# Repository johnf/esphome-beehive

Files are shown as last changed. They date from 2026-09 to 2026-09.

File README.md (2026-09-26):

# ESP32 Beehive Monitor

A battery-powered beehive monitoring system built with ESPHome. Uses FFT-based
audio analysis to detect colony health indicators, along with weight,
temperature, and humidity monitoring.

## Features

- **Audio Analysis**: FFT-based frequency band monitoring to detect queen
  piping, queenless conditions, and pre-swarm behaviour
- **Weight Monitoring**: Track hive weight changes using 4x 50kg load cells via
  NAU7802 ADC
- **Environmental Sensing**: Temperature and humidity via SHT40 sensor
- **Power Monitoring**: Solar current, voltage and power via INA226; battery voltage
  and state of charge via the FeatherS3D's onboard MAX17048 fuel gauge
- **Battery Optimised**: Deep sleep between 5-minute measurement cycles
- **Home Assistant Integration**: Automatic sensor discovery and state reporting

## Hardware Requirements

| Component | Description | Qty |
| --- | --- | ----- |
| [FeatherS3D](https://unexpectedmaker.com/feathers3d) (ESP32-S3) | Main microcontroller | 1 |
| INMP441 | I2S MEMS microphone (GPIO1, 3, 7) | 1 |
| [Adafruit NAU7802](https://www.adafruit.com/product/4538) | 24-bit ADC breakout | 1 |
| 50kg Load Cells | Half-bridge strain gauges | 4 |
| SHT40 | Temperature/humidity sensor | 1 |
| INA226 | Solar current/voltage/power monitor | 1 |
| CN3065 | Solar LiPo charge controller | 1 |
| [3.7V 2000mAh LiPo](https://core-electronics.com.au/polymer-lithium-ion-battery-2000mah-38459.html) | Battery (DW01+ PCM) | 1 |
| Solar panel | 6V nominal, 1W or larger (CN3065 input is rated for 6V panels) | 1 |
| Stripboard 24 x 41 holes | Main board (under the bottom board) | 1 |
| Stripboard 16 x 15 holes | Hive board (inside the brood box) | 1 |
| JST-XH 8-way socket and cable | Hive cable, one socket per board | 2 sockets, 1 cable |
| JST-XH 12-way socket and cable | Load cell socket (J_CELLS) | 1 |
| JST-XH 2-way socket | Solar in, charger in, charger out | 3 |
| JST-PH 2-way pigtail | CN3065 solar and output sockets | 2 |
| 100 nF ceramic capacitor | C2, C3 | 2 |
| 470 µF 6.3 V electrolytic capacitor | C1 | 1 |

## Power Architecture

The battery is charged by the CN3065 solar charge controller. An INA226 sits
high-side between the solar panel and the CN3065 solar input. The battery connects
directly to the CN3065 battery terminal.

The CN3065 output feeds the FeatherS3D's **VBAT pin**, so the board's own LDO
regulates 3.3V. Feeding the 3.3V pin instead would leave LDO2 unpowered, as its
input is the VBAT/USB node rather than the 3.3V rail.

The FeatherS3D's onboard charger only has power while USB is plugged in, so in the
field the CN3065 is the only charger. On USB, both chargers are 4.2V CC/CV parts and
share the cell harmlessly, with the DW01+ PCM as a backstop.

Battery voltage and state of charge come from the FeatherS3D's onboard MAX17048 fuel
gauge (I2C 0x36), which sees the cell via the VBAT pin. It sits on the always-on
LDO1 rail, so its ModelGauge state survives deep sleep.

The FeatherS3D's **LDO2** (GPIO39) provides a switchable 3.3V rail that is automatically
disabled during deep sleep, used to power-gate sensors that aren't needed during sleep.
All sensors, including the I2C pull-ups on their breakouts, are on this rail.

The INA226 address pins A0 and A1 are left unconnected. The CJMCU-226 module
has 10 kΩ pull-downs on both, which gives address 0x40. Confirm this on your
unit before building: unpowered, A0 to GND and A1 to GND should each read about
10 kΩ. If either reads open, strap that pad to GND.

CJMCU-226 modules come with two header pinouts: after ALE some read SDA then
SCL, others SCL then SDA. The Fritzing part (`fritzing/ina226/`) and the
stripboard layout follow the first, with SDA on pin 5. Check the silkscreen
before soldering the header; if yours is the other variant, do not plug the
module straight into its socket, but cross SDA and SCL with two short flying
leads.

### Solar Performance

The CN3065 regulates its own input voltage. In direct sun it held the panel at
4.77V for over an hour while the current drifted, well below the 6V maximum
power point of a nominal 6V panel. Panel power is therefore capped near 0.8W no
matter how much sun a 1W panel sees.

That cap matters less than it looks. The CN3065 is a linear charger, so it
passes current through roughly one-for-one and burns the voltage difference as
heat. Charge current, not panel watts, is what fills the cell.

Measured on a 110 x 60 mm 1W 6V polycrystalline panel in direct spring sun
(Sydney, sun about 52° above the horizon, panel not aimed):

| Quantity | Value |
|---|---|
| Panel voltage | 4.77V (clamped by the CN3065) |
| Panel current | 113-121 mA |
| Panel power | 0.54-0.58W |
| Fraction of nameplate | 55-58% |

At ~113 mA against an average draw of ~2.3 mA, roughly half an hour of direct
sun per day covers the device's entire daily consumption, and four good hours
put in over eight times what it uses. A 1W panel is ample for this load.

Siting buys far more than panel size. The same panel shaded and badly angled
produced 5-50 mW, one to two orders of magnitude below its direct-sun output,
and the battery fell 2.7% per day through it. If the battery is losing ground,
move the panel before buying a bigger one.

If you do want more margin, wire two panels in **parallel** to roughly double
the current at the clamped voltage. Series gains nothing, because the charger
regulates its input down regardless of what the panels could deliver.

### Battery Specifications

| Parameter | Value |
|---|---|
| Nominal voltage | 3.7V |
| Charge voltage | 4.2V (CN3065) |
| Overcharge protection | 4.30V ±0.05V (DW01+ PCM) |
| Over-discharge protection | 2.4V ±0.1V (DW01+ PCM) |
| Capacity | 2000mAh |
| Wiring/connector rating | 1A max |

### I2C Address Map

| Address | Device |
|---|---|
| 0x2A | NAU7802 (load cell ADC) |
| 0x36 | MAX17048 fuel gauge (onboard FeatherS3D) |
| 0x40 | INA226 (solar) |
| 0x44 | SHT40 (temperature/humidity) |

## Wiring

The circuit is split across two stripboards joined by a pluggable cable. The
Fritzing sketch `fritzing/BeeHive.fzz` is the design of record and its
breadboard view holds the stripboard layout. Both boards use vertical strips
(strips run top to bottom in the breadboard view) and hole coordinates below
are `(column, row)` counted from 0 at the top-left.

### Boards and Connectors

**Main board** (24 x 41, under the bottom board with the battery, CN3065 and
solar panel plug): FeatherS3D, INA226, NAU7802, C1, C2 and five sockets. The
Feather sits across the top with its 16-pin row on row 3 and 12-pin row on
row 11; every strip under those rows is cut above the top row and below the
bottom row (cuts `x.3v` and `x.10v` for columns 3-18 and 3-14) so the two rows
do not short, except column 15, which carries the Feather GND pin the full
height of the board as the ground rail. Column 2 is the 3.3 V rail, fed from
LDO2 (column 3, row 3) by the jumper on row 2.

Columns 2-9 run straight from the Feather's bottom row to J_HIVE on the bottom
edge (row 40), so 3V3, SDA, SCL, WS, SCK and SD reach the hive socket without a
jumper; columns 5 and 6 (IO33 and IO38, cut at `5.11v 6.11v`) become its two
ground pins via row 14. Everything else sits to the right of that corridor:
C1 and the VBAT tap at the top right, J_PWR on the right edge at row 15, the
INA226 with its header on row 18 (VCC, GND, SCL, SDA, ALE, VBS, IN-, IN+ on
columns 14-21, GND landing on the rail, C2 directly above it on row 17),
J_SOLAR and J_CHG on the right edge at rows 28 and 31, the NAU7802 with its
header on row 29 (DRDY, SDA, SCL, GND, AVDD, VCC on columns 12-17, GND on the
rail, screw terminal facing the bottom edge) and J_CELLS on the bottom edge
beside J_HIVE. Column 23 is a second ground rail for C1 and the three
right-edge sockets; column 22 carries VBAT, panel + and charger + in three
segments. Row 39 stays empty under the two bottom sockets.

| Row | Jumper | Net |
| --- | --- | --- |
| 2 | (3,2) → (2,2) | LDO2 to the 3.3 V rail |
| 12 | (14,12) → (22,12) | VBAT to C1 and J_PWR |
| 13 | (2,13) → (14,13) | 3.3 V to INA226 VCC and C2 |
| 13 | (15,13) → (23,13) | Ground to the right rail |
| 14 | (15,14) → (6,14) → (5,14) | Ground to J_HIVE pins 4 and 5 |
| 15 | (4,15) → (16,15) | SCL to the INA226 |
| 16 | (3,16) → (13,16) → (17,16) | SDA to the NAU7802 and INA226 |
| 26 | (14,26) → (17,26) | 3.3 V to NAU7802 VCC |
| 26 | (19,26) → (20,26) | INA226 VBS to IN- |
| 26 | (21,26) → (22,26) | INA226 IN+ to J_SOLAR + |
| 27 | (16,27) → (14,27) | SCL to the NAU7802 |
| 33 | (20,33) → (22,33) | INA226 IN- to J_CHG + |
| 38 | (12,38) → (13,38), (15,38) → (16,38), (18,38) → (19,38), (21,38) → (22,38) | Load cell ring, see [Load Cells](#load-cells) |
| 38 | (11,38), (14,38), (17,38), (20,38) | Flying leads into the NAU7802 screw terminal |

**Hive board** (16 x 15, inside the brood box): SHT40, INMP441, C3 and the
cable socket. It is wired up the inside of the hive and unplugs at the main
board.

| Socket | Board, holes | Pin 1 | Pin 2 | Pin 3 | Pin 4 | Pin 5 | Pin 6 | Pin 7 | Pin 8 |
| --- | --- | --- | --- | --- | --- | --- | --- | --- | --- |
| J_HIVE | Main (2-9, 40) | 3V3 | SDA | SCL | GND | GND | WS | SCK | SD |
| J_SUB | Hive (2-9, 1) | 3V3 | SDA | SCL | GND | GND | WS | SCK | SD |
| J_SOLAR | Main (22-23, 28) | Panel + | Panel - | | | | | | |
| J_CHG | Main (22-23, 31) | CN3065 SOLAR + | CN3065 SOLAR - | | | | | | |
| J_PWR | Main (22-23, 15) | CN3065 OUT + | CN3065 OUT - | | | | | | |
| J_CELLS | Main (11-22, 40) | 12 pins, see [Load Cells](#load-cells) | | | | | | | |

The hive cable is wired pin for pin. Ground sits between SCL and the I2S
clocks so the cable can run a metre or two. JST-XH is 2.5 mm pitch, which
fits the 2.54 mm stripboard grid with a little lean on the 8-way socket and
about half a millimetre over the 12-way. Every socket sits on a board edge, so
side-entry (S*B-XH-A) or top-entry (B*B-XH-A) housings both work.

The CN3065 module is not on the stripboard. Its three JST-PH sockets take the
panel current from J_CHG (after the INA226 shunt), the battery directly, and
send the output to J_PWR via short pigtails. The INA226 address pads A0 and A1
are left open; the module pulls them down (see Power Architecture).

Strip cuts on the main board beyond the Feather rows: `5.11v 6.11v` turn the
IO33 and IO38 strips into the J_HIVE grounds, `14.12v` separates VBAT from the
3.3 V segment that feeds the INA226, `13.15v 16.14v 17.15v` keep the SDA and
SCL taps off the Feather pins and pads above them, `17.25v 14.26v 16.27v
12.28v` split the INA226 columns from the NAU7802 header (VCC, SCL, AVDD and
DRDY), `22.15v 22.29v` divide column 22 into VBAT, panel + and charger +, and
`11.37v` to `22.37v` isolate the J_CELLS pins (rows 38-40) from everything
above them. On the hive board the cuts are `6.4v` (SHT40 VIN off the ground
strip) and `10.6v 11.6v` (the microphone's top and bottom pin rows). The
sketch has the jumper wires and exact placements; check the build against it
with `python3 .claude/skills/circuit/fzz_nets.py fritzing/BeeHive.fzz`.

### I2C Bus (SHT40, NAU7802, INA226, MAX17048)

The I2C bus must be defined in your device configuration and its `id` passed to the
package via the `i2c_bus_id` substitution (defaults to `i2c_bus`).

| Signal | Default GPIO |
| --- | --- |
| SDA | GPIO8 |
| SCL | GPIO9 |

### INMP441 Microphone

Pin assignments are configurable via substitutions (`i2s_lrclk_pin`, `i2s_bclk_pin`, `i2s_din_pin`).

| INMP441 Pin | Default ESP32 GPIO |
| --- | --- |
| WS (LRCLK) | GPIO1 |
| SCK (BCLK) | GPIO3 |
| SD (DOUT) | GPIO7 |
| VDD | 3.3V |
| GND | GND |
| L/R | GND (left channel) |

### Load Cells

Each 50kg half-bridge cell has three wires: red (centre tap), white and black.
All twelve go to J_CELLS, the 12-way JST-XH socket on the bottom edge of the
main board. The bridge is made on the board, so nothing is spliced at the
platform. Place one cell at each corner and number them 1 to 4 clockwise.

| J_CELLS pin | Wire | J_CELLS pin | Wire |
| --- | ---- | --- | ---- |
| 1 | Cell 1 red | 7 | Cell 3 red |
| 2 | Cell 1 white | 8 | Cell 3 white |
| 3 | Cell 2 white | 9 | Cell 4 white |
| 4 | Cell 2 red | 10 | Cell 4 red |
| 5 | Cell 2 black | 11 | Cell 4 black |
| 6 | Cell 3 black | 12 | Cell 1 black |

The jumpers on row 38 bridge pins 2-3, 5-6, 8-9 and 11-12, joining like
colours round the platform (white 1-2, black 2-3, white 3-4, black 4-1) into a
full Wheatstone bridge. Like must join like: in each cell the white and black
halves change in opposite directions under load, so a white-to-black ring
cancels in every bridge arm and the output barely moves. The four red wires
land on row 38 under the NAU7802 screw terminal and run into it with short
leads:

| Cell (red wire) | Row 38 hole | NAU7802 |
| --- | --- | --- |
| Cell 1 | (11,38) | E+ |
| Cell 2 | (14,38) | A- |
| Cell 3 | (17,38) | E- |
| Cell 4 | (20,38) | A+ |

E+ and E- are the bridge excitation (the breakout's AVDD and GND); A- and A+
are the channel A input. The B- and B+ terminals are the unused channel B.

If the weight reads negative when load is added, swap A+ and A-.

### Capacitors

| Ref | Value | Placement |
| --- | ----- | --- |
| C1 | 470 µF electrolytic, 6.3 V | VBAT and GND strips at the top right, main board (22-23, 11) |
| C2 | 100 nF ceramic | INA226 VCC and GND strips directly above its header, main board (14-15, 17) |
| C3 | 100 nF ceramic | INMP441 VDD and GND strips, hive board (11-12, 10) |

C1 stops WiFi transmit bursts browning out the LDO when the cell is cold or low.
C2 and C3 must sit right at the module pins; long wires in a beehive pick up
noise, and the INMP441 feeds the FFT analysis. The NAU7802 and SHT40 breakouts
have onboard decoupling already.

## Enclosure

`case/beehive-case.scad` is a parametric OpenSCAD model of two enclosures, with
exported STLs in `case/stl/`. Every dimension is a named variable at the top of
the file.

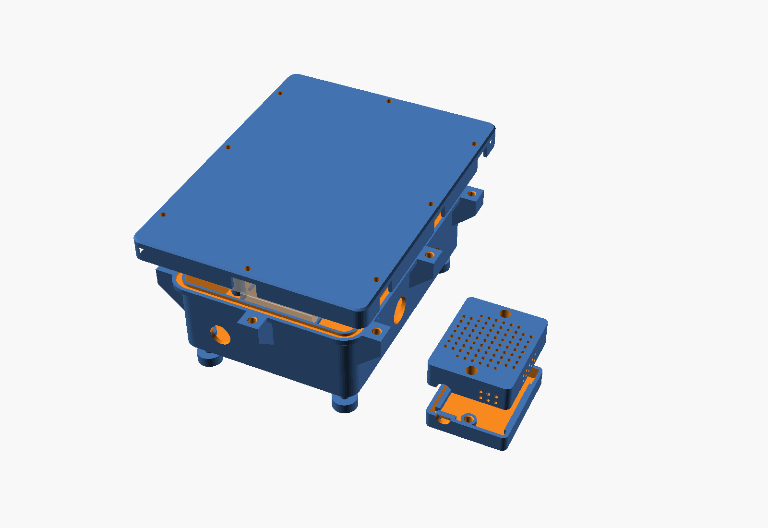
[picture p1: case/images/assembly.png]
Assembly


The `layout` view shows where the boards, battery and charger sit:

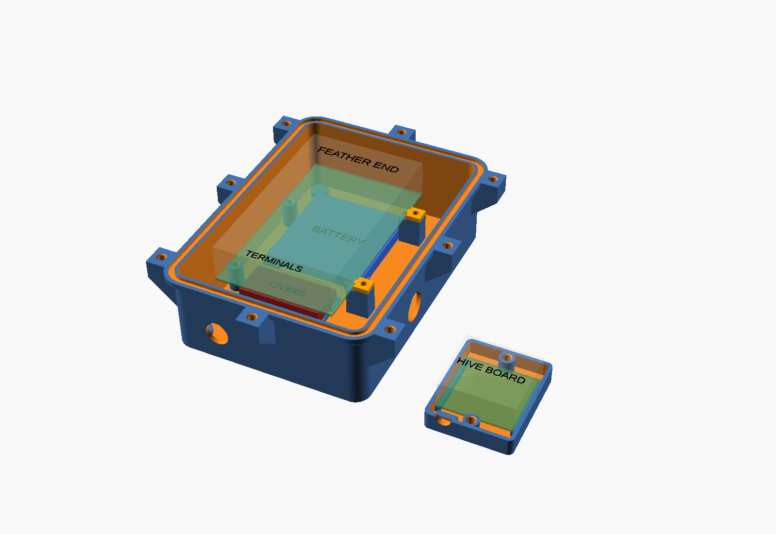
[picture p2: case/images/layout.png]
Layout

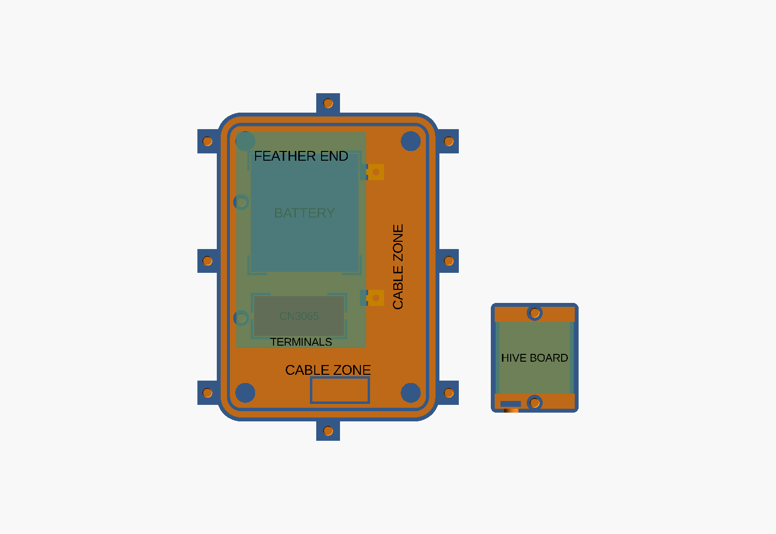
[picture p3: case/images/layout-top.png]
Layout from above


After changing a dimension, re-export the STLs and images:

```bash
cd case
for p in box lid clamp foot hive_base hive_lid; do
  openscad -D "part=\"$p\"" -o stl/$p.stl beehive-case.scad
done
openscad -D 'part="layout"' --camera=0,0,0,50,0,25,600 --viewall --autocenter \
  --imgsize=1600,1100 --colorscheme=Tomorrow -o images/layout.png beehive-case.scad
openscad -D 'part="layout"' --camera=0,0,0,0,0,0,600 --projection=ortho --viewall \
  --autocenter --imgsize=1600,1100 --colorscheme=Tomorrow -o images/layout-top.png \
  beehive-case.scad
openscad -D 'part="assembly"' --camera=0,0,0,50,0,25,600 --viewall --autocenter \
  --imgsize=1600,1100 --colorscheme=Tomorrow -o images/assembly.png beehive-case.scad
openscad -D 'part="seal_section"' --camera=0.99,37.98,0,0,0,0,40 --projection=ortho \
  --imgsize=1600,1100 --colorscheme=Tomorrow -o images/seal-section.png \
  beehive-case.scad
for p in hive_base hive_lid; do
  openscad -D "part=\"$([ $p = hive_lid ] && echo hive_lid_fitted || echo $p)\"" \
    --camera=0,0,0,50,0,25,150 --viewall --autocenter --imgsize=1600,1100 \
    --colorscheme=Tomorrow -o images/${p/_/-}.png beehive-case.scad
done
```

Then slice every STL with PrusaSlicer to catch parts that don't fit the bed or
need supports. `a1mini.ini` approximates the A1 mini with the settings below and
gives print times and filament use:

```bash
for p in box lid clamp foot hive_base hive_lid; do
  prusa-slicer --export-gcode --load a1mini.ini --center 90,90 \
    -o /tmp/$p.gcode stl/$p.stl 2>&1 | grep -A3 -i warning
done
```

`hive_lid` reports "Floating bridge anchors": that is the one-layer bridge over
each counterbore that you drill out, and it prints fine.

Open `beehive-case.scad` in OpenSCAD with `part = "layout"` to rotate the layout
view yourself. Colours only show in preview (F5), not in a full render (F6).

**Main box** sits under the hive and holds the main board, battery and CN3065.
The board rides on two M3 posts down its left edge and two printed clamps on its
right edge, with the battery and charger underneath. There is 30 mm clearance on
the terminal edges. Cables enter through two PG9 glands and a PG7 on one long wall; an
M12 ePTFE vent on the end wall lets it breathe without leaving a gap for ants. A
2.4 mm O-ring sits in a groove in the rim. The lid closes flush on the rim,
which squeezes the ring 25%, and screws into heat-set inserts in eight lugs. A
skirt under the lid locates it inside the walls, and a lip around its edge
stiffens it and keeps rain off the rim.

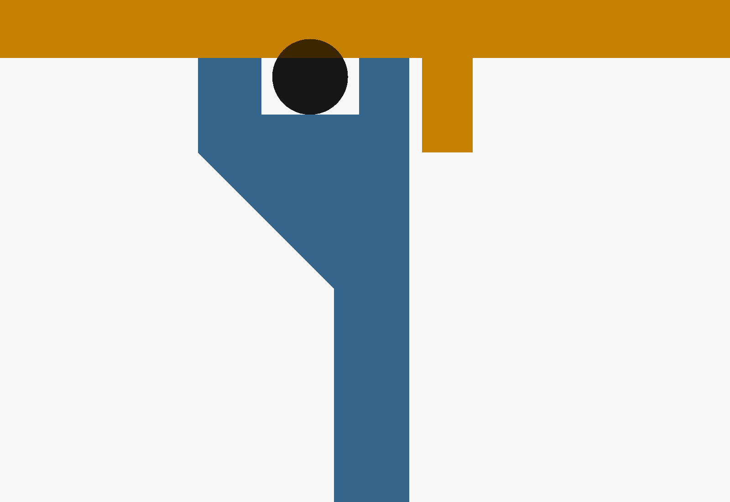
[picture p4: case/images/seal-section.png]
Seal cross-section


The seal is a 155 mm OD x 2.4 mm nitrile O-ring (about 150 mm ID). It stretches
about 2% to fit the groove, whose centre line is 488 mm (`groove_len`). A larger
2.4 mm ring or cord also works: cut it to 488 mm and butt-join the ends with
cyanoacrylate. For a different cross-section, change `oring_d`, `groove_depth`
(0.75 x the cross-section, rounded to a multiple of the layer height) and
`groove_w` (1.3 x).

**Hive housing** sits loose on the mesh floor inside the brood box. The base is
solid so the SHT40 reads hive air, not air through the mesh. The board rests on
ledges and ribs on the lid's side walls hold it down. The top and sides are a
grid of 2 mm holes, too small for bees. The Cat6 leaves through a notch at one
end, tied to an anchor.

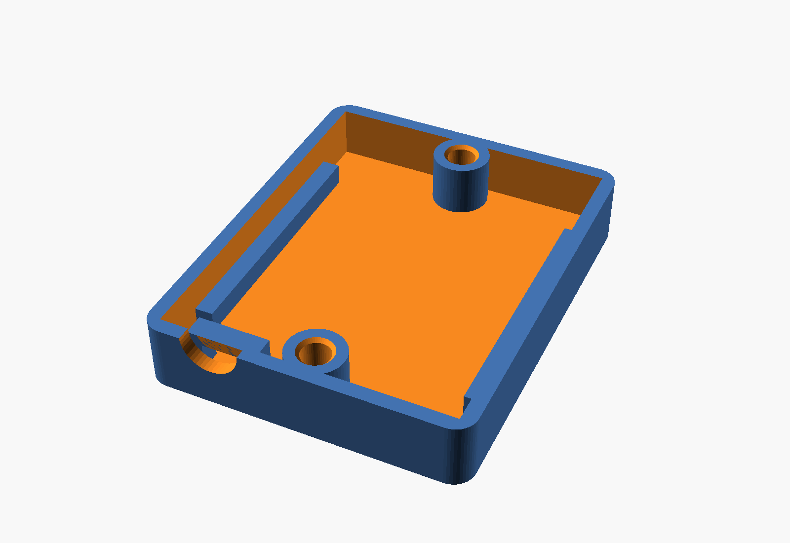
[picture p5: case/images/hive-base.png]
Hive housing base

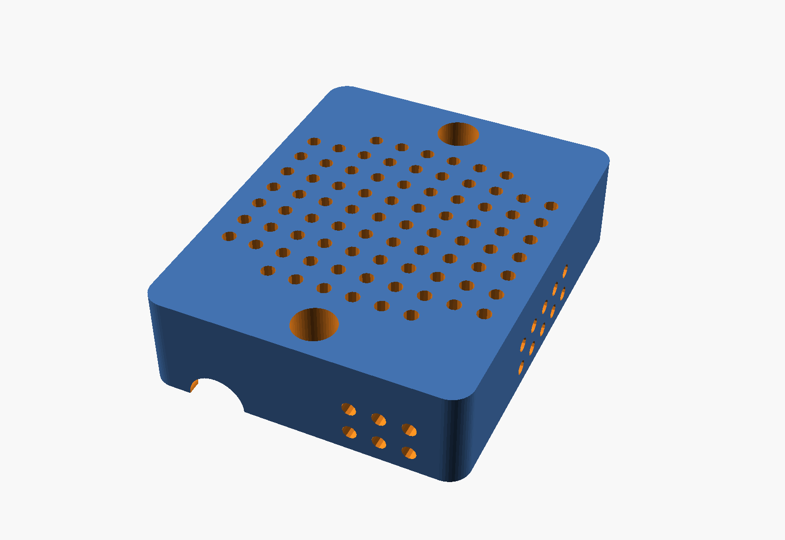
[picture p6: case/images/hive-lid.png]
Hive housing lid


Print in PLA, starting from the A1 mini 0.20 mm Standard profile with 4 wall
loops, 35% infill and no brim (`box` and `lid` are 175 mm long on a 180 mm
bed). Iron the top surface of `lid`, which is its sealing face. Print `lid` and
`hive_lid` as exported (outside face down). Each screw hole in `hive_lid` has a one-layer
bridge at the bottom of its counterbore; push a 3 mm drill through it after
printing. Press the heat-set inserts into the lid lugs, board posts, clamp
towers and hive housing posts with a soldering iron before assembly, flush or
just below the surface; the lid must sit flat on the lugs.

| Part | Qty |
| ---- | --- |
| `box`, `lid`, `hive_base`, `hive_lid` | 1 each |
| `clamp` | 2 |
| `foot` (glue into the floor) | 4 |
| PG9 cable gland, 4-8 mm (load cells, Cat6) | 2 |
| PG7 cable gland, 3-6.5 mm (solar) | 1 |
| M12 ePTFE breather vent | 1 |
| M3 x 10 socket head cap screw, stainless | 14 |
| M3 x 5.7 mm heat-set insert, 4.0 mm hole (e.g. ruthex) | 14 |
| O-ring, 155 mm OD x 2.4 mm, nitrile | 1 |
| Adhesive-lined heatshrink (load cell bundle, solar pair) | 2 |
| Silica gel sachet | 1 |
| Removable double-sided mounting strip (battery to floor, e.g. 3M Command) | 1 |

Drill the main board's two M3 holes in the outer left column, 15 mm and 73 mm
from the bottom edge. If you drill elsewhere, update `left_holes_y`.

## Installation

### Prerequisites

- Home Assistant with the ESPHome add-on installed

### Setup

1. **Create a new device in ESPHome**

   - Open the ESPHome dashboard in Home Assistant
   - Click **+ New Device**
   - Choose **Continue** then **Skip this step** (we'll use our own config)
   - Enter a name (e.g., `beehive-monitor`) and click **Next**
   - Select **ESP32** as the device type
   - Click **Skip** to skip the installation for now

2. **Edit the configuration**

   Click **Edit** on the new device and use the following configuration:

   ```yaml
   # Include the beehive monitoring package. `refresh: always` re-fetches the
   # default branch on every run instead of using ESPHome's cached copy.
   packages:
     beehive:
       url: https://github.com/johnf/esphome-beehive
       files: [beehive-monitor.yaml]
       refresh: always

   # Device configuration (required)
   esphome:
     name: beehive-monitor
     friendly_name: Beehive Monitor

   esp32:
     framework:
       type: esp-idf
     variant: esp32s3
     flash_size: 16MB  # FeatherS3D has 16MB flash

   psram:
     mode: quad
     speed: 80MHz

   # I2C bus (required - must define with id matching i2c_bus_id substitution)
   i2c:
     id: i2c_bus
     sda: GPIO8
     scl: GPIO9
     scan: true
     frequency: 400kHz

   # WiFi configuration (required)
   wifi:
     ssid: !secret wifi_ssid
     password: !secret wifi_password
     fast_connect: true

   # Home Assistant API (required)
   api:
     reboot_timeout: 0s

   # Optional: enable logging during development
   logger:
     hardware_uart: USB_CDC
     level: DEBUG

   # Optional: override default pin assignments, I2C addresses, calibration
   # or audio thresholds (see beehive-monitor.yaml for the full list)
   # substitutions:
   #   i2c_bus_id: "i2c_bus"
   #   i2s_lrclk_pin: "GPIO1"
   #   i2s_bclk_pin: "GPIO3"
   #   i2s_din_pin: "GPIO7"
   #   ina226_solar_address: "0x40"
   #   audio_active_threshold: "-95dB"
   ```

   A complete working example is in [example.yaml](example.yaml).

3. **Configure secrets**

   ESPHome uses Home Assistant's secrets. Add to your `secrets.yaml`:

   ```yaml
   wifi_ssid: 'YourWiFiNetwork'
   wifi_password: 'YourWiFiPassword'
   ```

   Or use the ESPHome Secrets editor (three-dot menu → **Secrets**).

4. **Install to the device**

   - Click **Install** on the device
   - For first-time installation, choose **Plug into this computer** or
     **Manual download** to get the firmware binary
   - Flash via USB using the web installer at <https://web.esphome.io/>
   - Subsequent updates can use **Wirelessly** once connected; see
     [OTA Updates](#ota-updates) for how to keep the device awake

### OTA Updates

The device is only awake for a few seconds every five minutes, which is not long
enough to install firmware wirelessly. The package therefore reads a Home
Assistant boolean helper on every wake and stays awake while it is on.

1. In Home Assistant, go to **Settings → Devices & services → Helpers**, create a
   **Toggle** helper and name it `Beehive OTA mode`, so its entity ID is
   `input_boolean.beehive_ota_mode`. Use the `ota_mode_entity` substitution if
   you pick a different name or run several hives.

   Then go to **Settings → Devices & services → ESPHome**, open the device's
   integration entry, click **Configure** and enable **Allow the device to
   perform Home Assistant actions**. The device needs this to clear the helper
   if it's left on (see below).
2. Turn the helper on. Within five minutes the device wakes, sees it, and logs
   `OTA mode - staying awake`. It keeps taking readings every
   `ota_mode_interval` (default five minutes); the **Measure Now** button
   starts a cycle straight away.
3. Click **Install → Wirelessly** in the ESPHome dashboard. Once an upload
   starts the device will not sleep until it reboots into the new firmware.
4. After the reboot the device stays awake while the helper is on, so you can
   watch the logs. Turn the helper off and the device goes back to sleep
   straight away.

If the helper is left on, the device clears it after `ota_mode_max_awake`
(default 30 minutes) and goes back to sleep. Without the actions permission
from step 1 the device still sleeps after the timeout, but stays awake again on
the next wake until you turn the helper off.

The package defines the `ota` component. To add a password or other options,
extend it in your device configuration rather than declaring a second one:

```yaml
ota:
  - id: !extend ota_esphome
    password: !secret ota_password
```

### Power Optimisation (recommended for battery operation)

For battery-powered deployments, add these settings to reduce power consumption:

```yaml
wifi:
  ssid: !secret wifi_ssid
  password: !secret wifi_password
  fast_connect: true
  power_save_mode: light
  # Static IP eliminates DHCP negotiation, saving 1-3 seconds per wake
  manual_ip:
    static_ip: 192.168.1.100  # Choose an IP outside your DHCP range
    gateway: 192.168.1.1      # Your router's IP
    subnet: 255.255.255.0

api:
  reboot_timeout: 0s  # Prevent reboots when Home Assistant is unavailable

# Disable UART logging in production
logger:
  level: WARN
  baud_rate: 0
```

## Calibration

### Load Cell Calibration

The package ships with placeholder calibration values that will not match your
load cells. Calibrate before trusting any weight reading.

1. Turn on [OTA mode](#ota-updates) so the device stays awake, and view the
   device logs in the ESPHome dashboard (click **Logs**). Each measurement
   cycle logs seven raw NAU7802 values; use the middle of the range. Cycles
   repeat every `ota_mode_interval` (default 5 minutes); set it to `10s` while
   calibrating for quicker readings, or press the **Measure Now** button on
   the device page in Home Assistant to start a cycle immediately
2. With no weight on the platform, note the raw value
3. Place a known weight on the platform and note the raw value. Use at least
   20 kg so the calibration spans a realistic hive weight; a second known
   weight (e.g. 40 kg) improves accuracy further
4. Let the platform settle for a minute after each change before reading
5. Click **Edit** on the device and set the calibration substitutions:

   ```yaml
   substitutions:
     weight_cal_raw_1: "<raw_empty>"
     weight_cal_kg_1: "0"
     weight_cal_raw_2: "<raw_20kg>"
     weight_cal_kg_2: "20"
     weight_cal_raw_3: "<raw_40kg>"
     weight_cal_kg_3: "40"
     weight_cal_raw_4: "<raw_40kg>"
     weight_cal_kg_4: "40"
   ```

   A least-squares line is fitted through the four points, so repeating a
   point is fine if you only have two known weights.

6. Click **Install** → **Wirelessly** to update the device

### Audio Baseline

Frequency band levels are reported as mean power spectral density in dB
relative to full scale (dB re FS²/Hz). This is independent of `fft_size` and
`frames`, so thresholds survive changes to those settings. Sound Level is
plain dBFS, measured above 60 Hz so the microphone's DC offset is excluded. The INMP441 reaches full scale at roughly 120 dB SPL, so add 120
to convert either figure to an approximate sound pressure level.

Each reading averages four consecutive FFT frames (about one second of audio).
Increase `audio_frames` for steadier band levels at the cost of awake time.

The Modulation Index and Modulation Frequency sensors come from a separate,
longer capture (`audio_modulation_duration`, default 10 s). Abdollahi et al.
(2026) found that the rate at which the buzz amplitude fluctuates predicts
colony strength far better than the average spectrum: weak colonies modulate
below 10 Hz, strong colonies spread up to about 35 Hz, and the 10-25 Hz range
is the most discriminating. The component takes a 100 ms / 12.5 ms hop STFT of
the 150-250 Hz band, then a second FFT over that envelope. Modulation Index is
the percentage of envelope power (1-40 Hz) that lies in 10-25 Hz, so it is
independent of microphone gain and colony loudness. Modulation Frequency is
the strongest modulation rate. Both are new and uncalibrated: log them for a
season alongside inspections before trusting them, and compare night-time
readings (roughly 8-11 pm, when foragers are home) rather than daytime ones.
The band and rate can be overridden with `modulation_band:` and
`modulation_rate:` blocks on the `bee_audio` component. Omit both modulation
sensors to skip the capture entirely and shorten awake time.

The classification thresholds are exposed as substitutions and will need
tuning for your microphone placement, hive size and background noise:

| Substitution | Default | Meaning |
|---|---|---|
| `audio_active_threshold` | -95dB | Worker band above this → `active` |
| `audio_normal_threshold` | -105dB | Baseline band above this → `normal`, below → `quiet` |
| `audio_queenless_threshold` | 6dB | Both queenless bands this far above baseline → `queenless` |
| `audio_queen_piping_threshold` | 10dB | Tooting or quacking this far above baseline → piping |
| `audio_pre_swarm_centroid` | 400Hz | Centroid above this while active → `pre_swarm` |
| `audio_modulation_duration` | 10s | Audio captured for the modulation spectrum (4-60 s) |

To tune, record the band sensors in Home Assistant for a few days and set
`audio_normal_threshold` between the quietest night-time baseline level and the
daytime level, and `audio_active_threshold` around the worker band level on a
busy afternoon. The band edges themselves can be overridden with a `bands:`
block on the `bee_audio` component, for example:

```yaml
bee_audio:
  bands:
    worker:
      low: 170Hz
      high: 280Hz
```

### Audio Baseline

The audio thresholds are set based on research values. You may need to adjust them in `components/bee_audio/bee_audio.cpp` based on:

- Microphone placement within the hive
- Hive size and colony population
- Background noise levels

## Sensors

### Frequency Bands

| Sensor | Frequency Range | Purpose |
|---|---|---|
| Low Frequency | 60-100 Hz | Low frequency content |
| Baseline Hum | 100-200 Hz | Normal colony activity |
| Worker Activity | 180-260 Hz | Worker bee flight |
| Queen Quacking | 200-350 Hz | Virgin queen in cell |
| Queen Tooting | 350-500 Hz | Emerged virgin queen |
| Queenless Mid | 478-677 Hz | Queenless indicator |
| Queenless High | 876-1080 Hz | Queenless indicator |

### Derived Metrics

| Sensor | Unit | Description |
|---|---|---|
| Dominant Frequency | Hz | Peak frequency in 60-600 Hz range |
| Sound Level | dB | RMS sound level above 60 Hz |
| Spectral Centroid | Hz | Centre of mass of spectrum |
| Modulation Index | % | Share of 150-250 Hz envelope power modulating at 10-25 Hz |
| Modulation Frequency | Hz | Strongest modulation rate of the 150-250 Hz envelope (1-40 Hz) |

### Power Monitoring

| Sensor | Unit | Description |
|---|---|---|
| Solar Bus Voltage | V | Solar panel voltage |
| Solar Current | A | Current from solar panel |
| Solar Power | W | Solar power input |
| Battery Voltage | V | Cell voltage from the MAX17048 |
| Battery Level | % | State of charge from the MAX17048 ModelGauge |
| Solar Producing | on/off | Solar current above `charging_current_threshold`. Panel output, not net battery current: the device draws more than the charger supplies during the wake window, so the battery only gains during deep sleep |

### Hive State Classification

The system classifies the hive into one of these states:

| State | Description |
|---|---|
| `quiet` | Very low activity, possibly night-time or cold |
| `normal` | Typical colony activity |
| `active` | Elevated worker activity |
| `queen_activity` | Queen piping detected (tooting or quacking) |
| `queenless` | Elevated mid/high frequency bands indicating queenless colony |
| `pre_swarm` | Elevated spectral centroid with high activity |

## Power Consumption

Indicative figures only; measure the real draw of your build with a meter in series
with the battery.

| State | Current Draw | Duration |
|---|---|---|
| Deep Sleep | ~10 µA (ESP32 only, sensor rail off) | 5 minutes |
| Active | ~150 mA | ~5-15 seconds (WiFi connect, ~1 s audio, ~1 s weight) |
| **Average** | **~2.3 mA** | - |

The average is measured, not estimated: the fuel gauge fell 2.7% per day over
three days with the panel shaded, which is about 54 mAh/day out of 2000 mAh.

**Note**: Any sensor not powered from LDO2 draws standby current during deep
sleep.

With a 2000 mAh battery and no solar input at all, that 2.7% per day works out
to roughly a month from full. Any reasonable sun keeps it topped up
indefinitely; see [Solar Performance](#solar-performance).

## Home Assistant

Once connected, sensors will automatically appear in Home Assistant.

[dashboard.yaml](dashboard.yaml) is a ready-made dashboard with overview, audio and
power views. Create a new dashboard from scratch, open **Edit dashboard → Raw
configuration editor**, and paste the file in. Entity IDs assume the device is
named `Beehive Monitor`; replace `beehive_monitor_` if yours differs.

Example automations:

```yaml
automation:
  - alias: 'Alert on Queenless Hive'
    trigger:
      - platform: state
        entity_id: text_sensor.beehive_monitor_hive_state
        to: 'queenless'
        for:
          hours: 1
    action:
      - service: notify.mobile_app
        data:
          title: 'Beehive Alert'
          message: 'Hive may be queenless - check colony!'

  # Piping is detected from a one-second sample every five minutes, so a
  # single detection may be noise. Require it to persist across two readings.
  - alias: 'Alert on Queen Piping'
    trigger:
      - platform: state
        entity_id: binary_sensor.beehive_monitor_queen_piping_detected
        to: 'on'
        for:
          minutes: 6
    action:
      - service: notify.mobile_app
        data:
          title: 'Beehive Alert'
          message: 'Queen piping detected - possible swarm preparation'
```

## Troubleshooting

### No audio data

- Check INMP441 wiring, especially L/R pin (must be grounded for left channel)
- Verify 3.3V power supply is stable
- Check I2S pin assignments in YAML

### Weight barely changes under load

- A raw value near zero that moves by only tens of counts when you lean on the
  platform means the bridge is cancelling itself. Check the outer wires are
  joined white to white and black to black (see [Load Cells](#load-cells));
  expect a thousand or more counts per kilogram when wired correctly
- Each cell must be free to flex: support the outer frame and load the centre
  boss, or the reverse. A cell sitting flat on a surface cannot bend

### Weight readings unstable

- Ensure load cells are properly mounted and not touching the frame
- Check for loose connections on the NAU7802
- Recalibrate with weights spanning the real hive weight range; extrapolating
  from a few kilograms magnifies noise
- Each reading is already the median of five raw samples; if the log shows
  "No measurements ready!" on every sample, check the NAU7802 power and I2C

### WiFi connection issues

- Enable `fast_connect: true` to skip scanning
- Position the ESP32 antenna away from metal components
- Consider adding an external antenna

### Deep sleep not working

- Check that `on_boot` script is executing (visible in logs)
- Check the OTA mode helper is off in Home Assistant
- Verify no other components are blocking sleep
- Ensure the `run_duration` is sufficient for sensor readings

### "ESPHome is not permitted to perform Home Assistant actions"

The device tried to clear the OTA mode helper after `ota_mode_max_awake`.
Enable **Allow the device to perform Home Assistant actions** on the device's
ESPHome integration entry (see [OTA Updates](#ota-updates)), then turn the
helper off.

### Battery slowly discharging

Compare Solar Power against the figures in
[Solar Performance](#solar-performance). Around 0.5W and 110 mA at midday is a
healthy 1W panel; tens of milliwatts means it is shaded or badly angled, which
is by far the most common cause.

- Check Solar Bus Voltage. Near the cell voltage means the panel is not driving
  the charger; around 4.8V means it is
- Reposition the panel before replacing it, and watch for shade that only falls
  across it for part of the day
- Solar Current is sampled only during the wake window, so what the panel does
  during deep sleep is invisible

## Development

Clone the repository and build the example configuration, which uses the
component from the local `components/` directory rather than the pinned
release:

```bash
cat > secrets.yaml <<'EOF'
wifi_ssid: my-ssid
wifi_password: my-password
EOF
esphome config example.yaml
esphome compile example.yaml
```

CI runs the same two commands on every push and pull request.

`setup-dev.sh` clones ESPHome, ESP-IDF and ESP-DSP into `cdeps/` so that
`clangd` can resolve headers when editing the C++ component.

### Releasing

There are no releases. Device configurations track the default branch and
re-fetch it on every run, so a push to `main` reaches devices on their next
build.

## Contributing

Contributions are welcome! Please open an issue or submit a pull request.

## References

- [Bee Audio Analysis Research](https://www.ncbi.nlm.nih.gov/pmc/articles/PMC7506584/) - Scientific basis for frequency bands
- [Abdollahi et al. 2026, Modulation Tensorgrams for Colony Strength](https://arxiv.org/abs/2607.20386) - Basis for the modulation spectrum sensors
- [ESPHome Documentation](https://esphome.io/)
- [ESP-DSP Library](https://github.com/espressif/esp-dsp)
- <https://how2electronics.com/how-to-use-ina226-dc-current-sensor-with-arduino/>

## Licence

ISC License - See [LICENSE](LICENSE) for details.

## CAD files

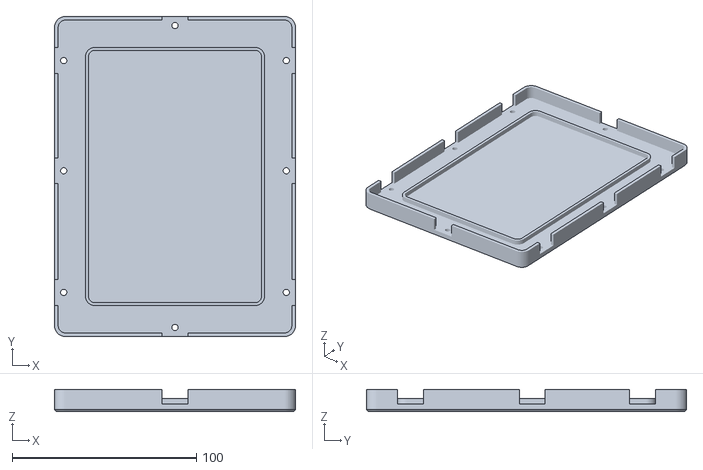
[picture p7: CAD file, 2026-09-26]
case/stl/lid.stl
130.8 x 173.8 x 12.0

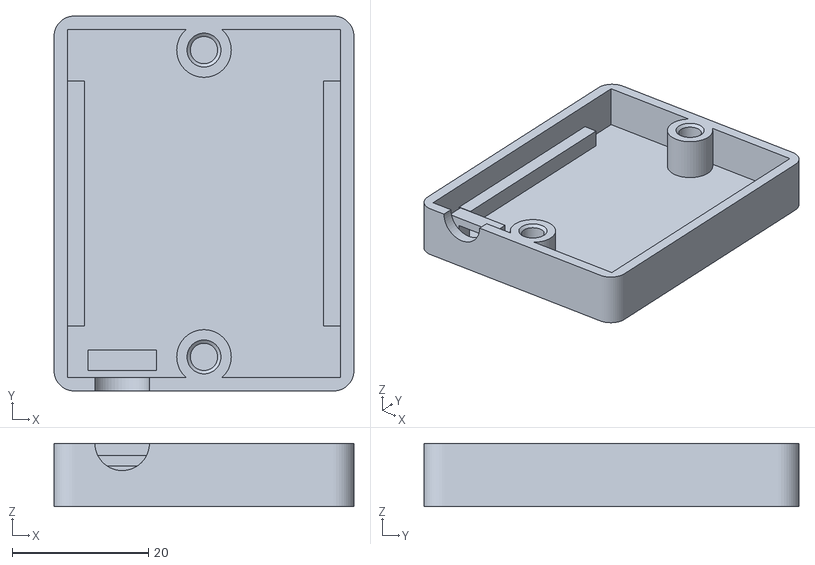
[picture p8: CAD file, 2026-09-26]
case/stl/hive_base.stl
44.0 x 55.0 x 9.30

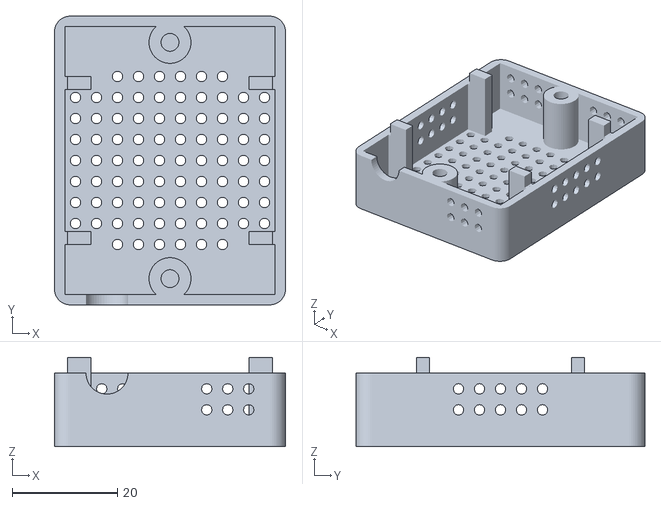
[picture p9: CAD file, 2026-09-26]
case/stl/hive_lid.stl
44.0 x 55.0 x 17.0

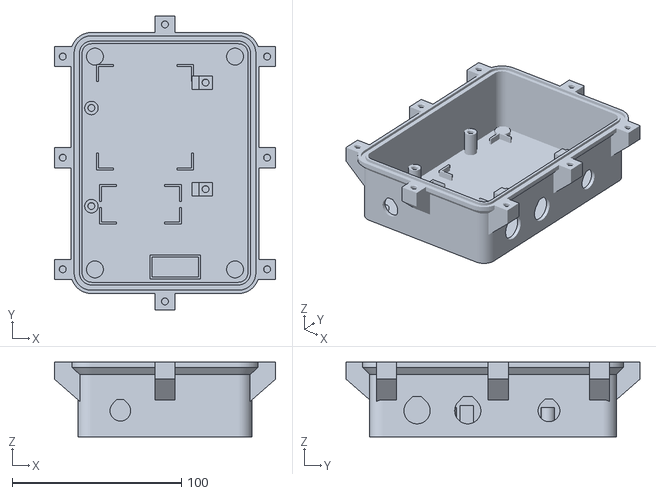
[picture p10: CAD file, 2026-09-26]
case/stl/box.stl
130.8 x 173.8 x 44.1

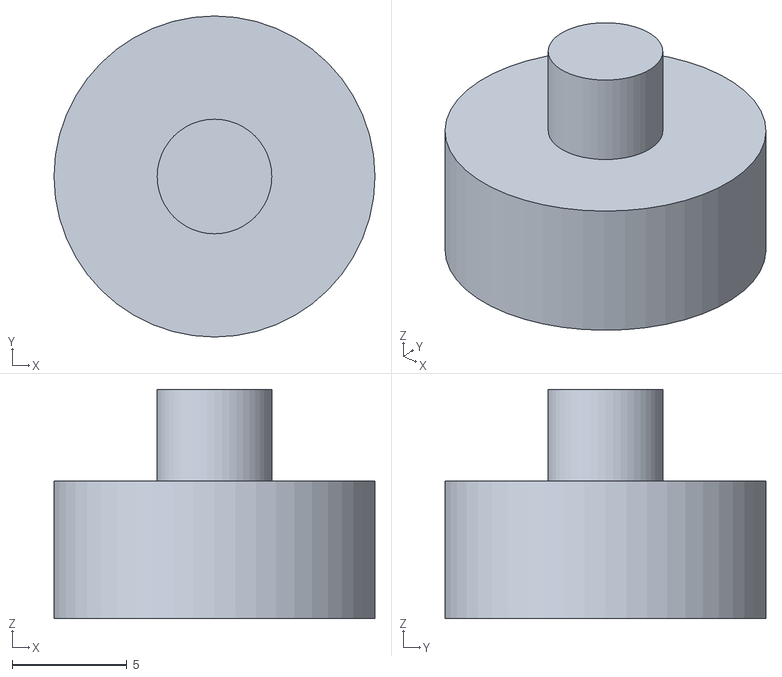
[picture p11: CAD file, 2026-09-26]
case/stl/foot.stl
14.0 x 14.0 x 10.0

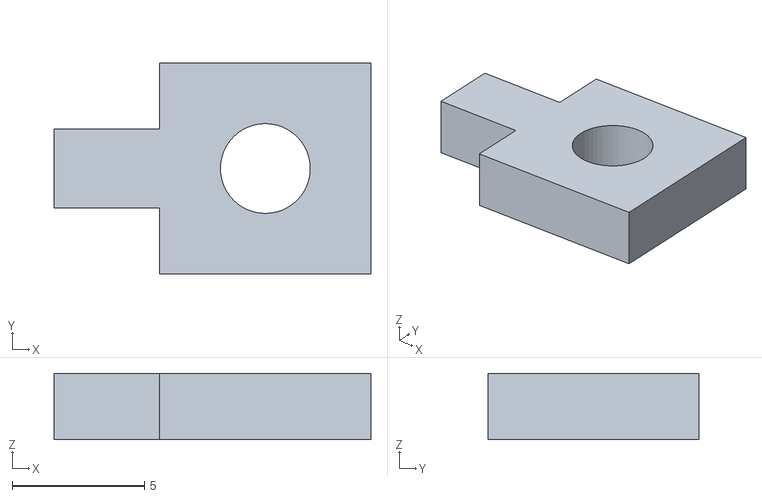
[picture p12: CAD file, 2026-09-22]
case/stl/clamp.stl
12.0 x 8.00 x 2.50

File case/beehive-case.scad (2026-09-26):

// Beehive monitor enclosures. Export one part at a time, e.g.
//   openscad -D 'part="box"' -o stl/box.stl beehive-case.scad
// Parts: box, lid, clamp, foot, hive_base, hive_lid
// Views: assembly, layout, seal_section, hive_lid_fitted

part = "assembly";

$fn = 48;
eps = 0.01;
layer_h = 0.2;

/* ---------- Main box ---------- */

wall = 2.4;
floor_t = 2.4;
corner_r = 8;               // keeps the O-ring bend radius above 3x its diameter

board = [65, 108];
board_t = 1.3;
board_gap = 3;              // left and top edges
connector_clearance = 30;   // right and bottom (terminal) edges
board_z = 15;               // board underside above the floor
component_h = 20;
headroom = 5.4;

inner = [
  board_gap + board[0] + connector_clearance,
  board_gap + board[1] + connector_clearance,
  board_z + board_t + component_h + headroom
];
outer = [inner[0] + 2 * wall, inner[1] + 2 * wall, inner[2] + floor_t];

// Board in inner coordinates; y runs from the bottom (terminal) edge.
board_pos = [board_gap, connector_clearance];
board_right = board_pos[0] + board[0];

// Left edge M3 holes, measured from the board's left and bottom edges
left_hole_inset = 2.5;
left_holes_y = [15, board[1] - 35];
post_d = 8;
insert_d = 4;               // M3 x 5.7 heat-set insert
insert_depth = 9;           // room for M3 x 10 screws past the insert
insert_chamfer = 0.5;       // catches plastic displaced when pressing

// Right edge clamps, measured from the board's bottom edge
clamps_y = [25, board[1] - 20];
clamp_w = 8;
clamp_ledge = 3;            // support under the board
clamp_gap = 1;              // board edge to clamp column
clamp_col = 8;
clamp_t = 2.5;
clamp_finger = [3, 3];      // overlap onto the board, width
clamp_preload = 0.3;
tower_top = board_z + board_t - clamp_preload;

battery = [54, 59, 6];
battery_pos = [10.25, 68];
charger = [45, 20, 8];      // CN3065
charger_pos = [12, 36];
guide_t = 1.2;
guide_len = 10;
guide_clr = 0.5;

silica_pos = [40, 2];
silica = [30, 14, 6];

// Glands on the +x wall: load cells (PG9), Cat6 (PG9), solar (PG7)
gland_d = [15.5, 15.5, 12.9];
gland_y = [28, 58, 106];
gland_z = floor_t + 13;

// M12 ePTFE vent on the -y wall
vent_d = 12.2;
vent_x = 25;
vent_z = floor_t + 13;
hole_cap = 0.6;             // flat top above the gland and vent holes, kept under their seals

// Lid lugs with heat-set inserts
lug_depth = 14;
lug_w = 12;
lug_h = 10;
lug_y = [10, 76, outer[1] - 10];  // long sides; middle off-centre to clear the glands
lug_end_x = outer[0] / 2;                     // one on each short side
screw_offset = 9;
screw_clear_d = 3.4;

// Face-seal O-ring cord in a groove in the rim, 25% squeeze with the lid flush
oring_d = 2.4;
groove_depth = 1.8;         // multiple of layer_h
groove_w = 3.1;
groove_land = 1.6;          // inner wall face to groove
groove_outer_land = 2;
rim_ext = groove_land + groove_w + groove_outer_land - wall;
rim_t = groove_depth + 1.2;

lid_t = 4;
lid_r = 6;
lid_chamfer = 1;
skirt_t = 1.6;
skirt_h = 3;
skirt_clr = 0.4;
lip_h = 8;                  // downturned edge: stiffens the lid and sheds rain off the rim
lip_t = 2;
lip_clr = 1;                // gap beside each lug

groove_offset = groove_land + groove_w / 2;
groove_r = corner_r - wall + groove_offset;
groove_len = 2 * (inner[0] + inner[1] + 4 * groove_offset) - 8 * groove_r + 2 * PI * groove_r;
echo(str("O-ring cord length: ", round(groove_len), " mm"));

// Glued-in feet
foot_d = 14;
foot_h = 6;
foot_peg_d = 5;
foot_peg_h = 4;
foot_hole_d = 5.3;
foot_inset = 10;
foot_boss_d = 10;
foot_boss_h = 3;
foot_pos = [
  [foot_inset, foot_inset],
  [outer[0] - foot_inset, foot_inset],
  [foot_inset, outer[1] - foot_inset],
  [outer[0] - foot_inset, outer[1] - foot_inset]
];

/* ---------- Hive board housing ---------- */

hive_board = [39, 36];
hive_component_h = 14;
hive_solder = 3;
hwall = 2;
hfloor = 2;
htop = 2;
hclr = 0.5;
hboss_zone = 7;
hinner = [
  hive_board[0] + 2 * hclr,
  hive_board[1] + 2 * hclr + 2 * hboss_zone,
  hive_solder + board_t + hive_component_h + 1
];
houter = [hinner[0] + 2 * hwall, hinner[1] + 2 * hwall, hinner[2] + hfloor + htop];
hboard_pos = [hclr, hboss_zone + hclr];
hboard_top = hive_solder + board_t;
hsplit = hboard_top + 3;
hledge_w = 2;
hpost_d = 8;
hpost_y = [hpost_d / 2 - 1, hinner[1] - hpost_d / 2 + 1];  // set into the end walls to clear the board
htube_d = 8;
hcbore_d = 6;
hcbore_floor = 3;
hrib = 2.5;
hrib_inset = 2;
hcable_d = 8;
hcable_x = 8;
hhole_d = 2;
hhole_pitch = 4;

/* ---------- Helpers ---------- */

module rrect(p0, p1, r) {
  translate(p0) translate([r, r]) offset(r = r) square([p1[0] - p0[0] - 2 * r, p1[1] - p0[1] - 2 * r]);
}

// Side-wall hole, point up: a 45° teardrop cut flat just above the circle prints without support
module wall_hole(d) {
  intersection() {
    hull() {
      circle(d = d);
      translate([0, d / 2 * sqrt(2)]) square(eps, center = true);
    }
    translate([-d, -d]) square([2 * d, 1.5 * d + hole_cap]);
  }
}

// Top of the hole at the origin
module insert_hole(depth = insert_depth) {
  translate([0, 0, -depth]) cylinder(d = insert_d, h = depth + eps);
  translate([0, 0, -insert_chamfer]) cylinder(d1 = insert_d, d2 = insert_d + 2 * insert_chamfer, h = insert_chamfer + eps);
}

module to_inner() {
  translate([wall, wall, floor_t]) children();
}

module corner_guides(pos, size, h) {
  x0 = pos[0] - guide_clr;
  y0 = pos[1] - guide_clr;
  x1 = pos[0] + size[0] + guide_clr;
  y1 = pos[1] + size[1] + guide_clr;
  for (c = [[x0, y0, 1, 1], [x1, y0, -1, 1], [x0, y1, 1, -1], [x1, y1, -1, -1]]) {
    translate([c[0], c[1], 0]) {
      translate([c[2] < 0 ? 0 : -guide_t, c[3] < 0 ? -guide_len + guide_t : -guide_t, 0])
        cube([guide_t, guide_len, h]);
      translate([c[2] < 0 ? -guide_len + guide_t : -guide_t, c[3] < 0 ? 0 : -guide_t, 0])
        cube([guide_len, guide_t, h]);
    }
  }
}

/* ---------- Main box parts ---------- */

module shell() {
  difference() {
    linear_extrude(outer[2]) rrect([0, 0], [outer[0], outer[1]], corner_r);
    translate([0, 0, floor_t])
      linear_extrude(outer[2]) rrect([wall, wall], [outer[0] - wall, outer[1] - wall], corner_r - wall);
  }
}

module lug() {
  back = wall - 0.4;  // into the wall, so corner lugs meet its curve
  difference() {
    hull() {
      translate([-back, 0, lug_depth]) cube([lug_depth + back, lug_w, lug_h]);
      translate([-back, 0, 0]) cube([eps, lug_w, eps]);
    }
    translate([screw_offset, lug_w / 2, lug_depth + lug_h]) insert_hole();
  }
}

module lugs() {
  z = outer[2] - lug_h - lug_depth;
  for (y = lug_y) {
    translate([outer[0], y - lug_w / 2, z]) lug();
    translate([0, y + lug_w / 2, z]) rotate([0, 0, 180]) lug();
  }
  translate([lug_end_x - lug_w / 2, 0, z]) rotate([0, 0, -90]) lug();
  translate([lug_end_x + lug_w / 2, outer[1], z]) rotate([0, 0, 90]) lug();
}

lid_screws = concat(
  [for (y = lug_y) for (x = [-screw_offset, outer[0] + screw_offset]) [x, y]],
  [[lug_end_x, -screw_offset], [lug_end_x, outer[1] + screw_offset]]
);

module inner_outline() {
  rrect([wall, wall], [outer[0] - wall, outer[1] - wall], corner_r - wall);
}

module rim() {
  z0 = outer[2] - rim_t;
  difference() {
    hull() {
      translate([0, 0, z0 - rim_ext]) linear_extrude(eps) rrect([0, 0], [outer[0], outer[1]], corner_r);
      translate([0, 0, z0]) linear_extrude(rim_t) offset(r = rim_ext) rrect([0, 0], [outer[0], outer[1]], corner_r);
    }
    translate([0, 0, z0 - rim_ext - 1]) linear_extrude(rim_t + rim_ext + 2) inner_outline();
  }
}

module oring_groove() {
  translate([0, 0, outer[2] - groove_depth]) linear_extrude(groove_depth + 1) difference() {
    offset(r = groove_land + groove_w) inner_outline();
    offset(r = groove_land) inner_outline();
  }
}

module clamp_tower() {
  translate([board_right - clamp_ledge, -clamp_w / 2, 0])
    cube([clamp_ledge + clamp_gap + clamp_col, clamp_w, board_z]);
  translate([board_right + clamp_gap, -clamp_w / 2, 0])
    cube([clamp_col, clamp_w, tower_top]);
}

module inner_features() {
  for (y = left_holes_y)
    translate([board_pos[0] + left_hole_inset, board_pos[1] + y, 0]) cylinder(d = post_d, h = board_z);
  for (y = clamps_y)
    translate([0, board_pos[1] + y, 0]) clamp_tower();
  corner_guides(battery_pos, battery, 4);
  corner_guides(charger_pos, charger, 2);
  translate(silica_pos) difference() {
    cube(silica);
    translate([guide_t, guide_t, -eps]) cube([silica[0] - 2 * guide_t, silica[1] - 2 * guide_t, silica[2] + 1]);
  }
}

module inner_holes() {
  for (y = left_holes_y)
    translate([board_pos[0] + left_hole_inset, board_pos[1] + y, board_z]) insert_hole();
  for (y = clamps_y)
    translate([board_right + clamp_gap + clamp_col / 2, board_pos[1] + y, tower_top]) insert_hole();
}
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

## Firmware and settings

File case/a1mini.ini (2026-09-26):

# Approximation of Bambu A1 mini, 0.4 nozzle, "0.20mm Standard", PLA Basic, 4 walls, 35% infill
bed_shape = 0x0,180x0,180x180,0x180
max_print_height = 180
nozzle_diameter = 0.4
filament_diameter = 1.75
filament_density = 1.24
layer_height = 0.2
first_layer_height = 0.2
perimeters = 4
top_solid_layers = 5
bottom_solid_layers = 3
fill_density = 35%
fill_pattern = grid
top_fill_pattern = monotonic
bottom_fill_pattern = monotonic
extrusion_width = 0.42
external_perimeter_extrusion_width = 0.42
first_layer_extrusion_width = 0.5
max_volumetric_speed = 21
external_perimeter_speed = 200
perimeter_speed = 300
small_perimeter_speed = 50
infill_speed = 270
solid_infill_speed = 250
top_solid_infill_speed = 200
gap_fill_speed = 250
bridge_speed = 50
travel_speed = 700
first_layer_speed = 50
first_layer_speed_over_raft = 50
default_acceleration = 10000
perimeter_acceleration = 5000
external_perimeter_acceleration = 5000
infill_acceleration = 10000
solid_infill_acceleration = 7000
top_solid_infill_acceleration = 2000
bridge_acceleration = 5000
first_layer_acceleration = 500
travel_acceleration = 10000
machine_limits_usage = time_estimate_only
machine_max_acceleration_extruding = 10000
machine_max_acceleration_retracting = 5000
machine_max_acceleration_travel = 10000
machine_max_acceleration_x = 10000
machine_max_acceleration_y = 10000
machine_max_acceleration_z = 1500
machine_max_acceleration_e = 5000
machine_max_feedrate_x = 500
machine_max_feedrate_y = 500
machine_max_feedrate_z = 20
machine_max_feedrate_e = 30
machine_max_jerk_x = 9
machine_max_jerk_y = 9
machine_max_jerk_z = 3
machine_max_jerk_e = 3
retract_length = 0.8
retract_speed = 30
support_material = 0
brim_width = 0
skirts = 0
gcode_flavor = marlin2

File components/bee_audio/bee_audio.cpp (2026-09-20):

#include "bee_audio.h"
#include "esphome/core/application.h"
#include "esphome/core/log.h"
#include <algorithm>
#include <cinttypes>
#include <cmath>
#include <cstring>

namespace esphome {
namespace bee_audio {

static const char *const TAG = "bee_audio";

static const char *const BAND_NAMES[BAND_COUNT] = {
    "low_freq", "baseline",      "worker",        "quacking",
    "tooting",  "queenless_mid", "queenless_high"};

// Floor for log10 of power values, keeps silence finite (-200 dB)
static const float POWER_FLOOR = 1e-20f;

// INMP441 outputs 24-bit data left-justified in a 32-bit word
static const float SAMPLE_SCALE = 1.0f / 8388608.0f; // 2^23

// Modulation spectrum STFT: 100 ms window, 12.5 ms hop (Abdollahi et al.)
static const uint32_t STFT_WINDOWS_PER_SECOND = 10;
static const uint32_t STFT_HOPS_PER_SECOND = 80;
// Second-stage FFT over the band envelope: 256 hops (3.2 s), 50% overlap
static const size_t MOD_SEGMENT = 256;
static const size_t MOD_HOP = MOD_SEGMENT / 2;
// Modulation rates below this are treated as drift rather than buzz dynamics
static const float MOD_MIN_HZ = 1.0f;

static size_t next_power_of_two(size_t n) {
  size_t p = 1;
  while (p < n) {
    p <<= 1;
  }

  return p;
}

BeeAudioComponent::~BeeAudioComponent() {
  this->deinit_i2s_();
  this->free_buffers_();
}

void BeeAudioComponent::setup() {
  ESP_LOGD(TAG, "Setting up Bee Audio...");

  if (this->fft_size_ == 0 || (this->fft_size_ & (this->fft_size_ - 1)) != 0) {
    ESP_LOGE(TAG, "FFT size must be power of 2, got %zu", this->fft_size_);
    this->mark_failed();

    return;
  }

  this->freq_resolution_ = static_cast<float>(this->sample_rate_) /
                           static_cast<float>(this->fft_size_);
  ESP_LOGD(TAG, "Frequency resolution: %.2f Hz/bin", this->freq_resolution_);

  if (!this->allocate_buffers_()) {
    this->mark_failed();

    return;
  }

  dsps_wind_hann_f32(this->window_, this->fft_size_);
  this->window_power_sum_ = 0.0f;
  for (size_t i = 0; i < this->fft_size_; i++) {
    this->window_power_sum_ += this->window_[i] * this->window_[i];
  }

  size_t fft_table_size = this->fft_size_;
  if (this->modulation_enabled_()) {
    this->stft_window_ = this->sample_rate_ / STFT_WINDOWS_PER_SECOND;
    this->stft_hop_ = this->sample_rate_ / STFT_HOPS_PER_SECOND;
    this->stft_fft_size_ = next_power_of_two(this->stft_window_);
    this->envelope_len_ =
        (this->modulation_duration_ms_ * STFT_HOPS_PER_SECOND) / 1000;
    if (this->envelope_len_ < MOD_SEGMENT) {
      ESP_LOGE(TAG, "Modulation duration too short: need at least %u ms",
               static_cast<unsigned>(MOD_SEGMENT * 1000 / STFT_HOPS_PER_SECOND));
      this->free_buffers_();
      this->mark_failed();

      return;
    }
    if (!this->allocate_modulation_buffers_()) {
      this->free_buffers_();
      this->mark_failed();

      return;
    }
    dsps_wind_hann_f32(this->stft_window_fn_, this->stft_window_);
    dsps_wind_hann_f32(this->mod_window_fn_, MOD_SEGMENT);
    fft_table_size = std::max(fft_table_size, this->stft_fft_size_);
  }

  // The twiddle table is bit-reversed, so one table sized for the largest
  // FFT also serves every smaller power-of-two length
  esp_err_t ret = dsps_fft2r_init_fc32(nullptr, fft_table_size);
  if (ret != ESP_OK) {
    ESP_LOGE(TAG, "FFT init failed: %s", esp_err_to_name(ret));
    this->free_buffers_();
    this->mark_failed();

    return;
  }
  this->fft_initialised_ = true;

  if (!this->init_i2s_()) {
    this->free_buffers_();
    this->mark_failed();

    return;
  }

  ESP_LOGCONFIG(TAG, "Bee Audio initialised successfully");
}

void BeeAudioComponent::update() {
  ESP_LOGD(TAG, "Starting audio capture and analysis...");

  if (!this->capture_and_analyse_()) {
    ESP_LOGW(TAG, "Audio capture failed");
    this->status_set_warning();

    return;
  }
  this->status_clear_warning();

  for (uint8_t b = 0; b < BAND_COUNT; b++) {
    this->band_power_[b] = this->calculate_band_power_(this->bands_[b]);
    if (this->band_sensors_[b] != nullptr) {
      this->band_sensors_[b]->publish_state(this->band_power_[b]);
    }
  }

  float centroid = this->calculate_spectral_centroid_();

  if (this->dominant_frequency_sensor_ != nullptr) {
    this->dominant_frequency_sensor_->publish_state(
        this->calculate_dominant_frequency_());
  }

  if (this->sound_level_rms_sensor_ != nullptr) {
    this->sound_level_rms_sensor_->publish_state(this->rms_db_);
  }

  if (this->spectral_centroid_sensor_ != nullptr) {
    this->spectral_centroid_sensor_->publish_state(centroid);
  }

  bool piping = this->detect_queen_piping_();
  if (piping) {
    ESP_LOGD(TAG, "Queen piping detected! Tooting: %.1f dB, Quacking: %.1f dB "
                  "above baseline",
             this->band_power_[BAND_TOOTING] - this->band_power_[BAND_BASELINE],
             this->band_power_[BAND_QUACKING] - this->band_power_[BAND_BASELINE]);
  }
  if (this->queen_piping_sensor_ != nullptr) {
    this->queen_piping_sensor_->publish_state(piping);
  }

  if (this->hive_state_sensor_ != nullptr) {
    HiveState state = this->classify_hive_state_(centroid);
    this->hive_state_sensor_->publish_state(hive_state_to_string_(state));
  }

  if (this->modulation_enabled_()) {
    if (this->capture_modulation_()) {
      this->analyse_envelope_();
      ESP_LOGD(TAG, "Modulation index: %.1f%%, peak modulation: %.1f Hz",
               this->modulation_index_, this->modulation_frequency_);
      if (this->modulation_index_sensor_ != nullptr) {
        this->modulation_index_sensor_->publish_state(this->modulation_index_);
      }
      if (this->modulation_frequency_sensor_ != nullptr) {
        this->modulation_frequency_sensor_->publish_state(
            this->modulation_frequency_);
      }
    } else {
      ESP_LOGW(TAG, "Modulation capture failed");
      this->status_set_warning();
    }
  }

  ESP_LOGD(TAG, "Audio analysis complete");
}
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

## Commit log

2026-01-25 refactor(bee_audio): improve resource management and performance
    - Add destructor for proper I2S and buffer cleanup
    - Validate FFT size is power of 2 during setup
    - Cache band powers once per update cycle instead of recalculating
    - Add buffer sizes to allocation error messages for debugging
    - Use inline constexpr for frequency band constants (C++17)
    - Fix typo: "grabage" → "garbage"
    - Ensure free_buffers_() is called on allocation failures
    [bee_audio.cpp]
2026-01-25 docs: fix I2S BCLK pin assignment and add configurable parameters
    Update CLAUDE.md and README.md to reflect the correct I2S BCLK pin
    (GPIO32 instead of GPIO26). Add documentation for configurable
    sample_rate and fft_size parameters in CLAUDE.md.
    Also includes minor formatting fixes in bee_audio.cpp.
    [bee_audio.cpp]
2026-01-25 refactor: convert beehive-monitor.yaml to reusable ESPHome package
    Move device-specific configuration to user responsibility:
    - Remove esphome name/friendly_name, esp32, wifi, api, logger sections
    - Users now include this as a package and provide their own config
    Enable power optimisations by default:
    - Enable deep_sleep component (was commented out)
    - Set sensor update_interval to never (manual trigger only)
    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
2026-01-25 fix: add SHT4x sensor to measurement cycle
    The temperature/humidity sensor was not being explicitly updated in the
    collect_and_sleep script. Add id and update_interval: never to match
    other sensors, and include in the measurement script.
2026-01-31 refactor: expose I2C bus and I2S pins as configurable substitutions
    Remove hardcoded i2c bus definition from the package so users define
    their own bus externally and pass the id via i2c_bus_id substitution.
    Expose I2S GPIO pins (LRCLK, BCLK, DIN) as substitutions with updated
    defaults (GPIO1, 3, 7). Update README and CLAUDE.md with usage examples.
2026-01-31 feat: add prevent deep sleep switch for OTA updates and debugging
    Add a Home Assistant-controllable template switch that prevents deep
    sleep, allowing OTA updates and debugging. When enabled, the device
    stays awake and continues collecting sensor data every 5 minutes.
2026-01-31 feat: disable deep sleep when GPIO pin is high at boot
    Add a configurable GPIO pin (default GPIO11) with pulldown that
    prevents deep sleep when held high during boot, enabling OTA updates
    and debugging without Home Assistant access.
2026-04-13 feat: add fritzing schematic
    [BeeHive.fzz]
2026-04-13 feat: add INA226 power monitoring, LDO2 sensor power gating, and battery level estimation
    - Add dual INA226 current/voltage/power sensors (solar 0x40, battery 0x45)
    with configurable I2C addresses via substitutions
    - Add sensor power switch (GPIO39/LDO2) owned by the package, with
    on_boot at priority 750 to power sensors before I2C setup runs
    - Add battery level sensor derived from INA226 bus voltage using a
    LiPo discharge curve (DW01+ PCM: 4.30V overcharge, 2.4V cutoff)
    - Fix boot sequencing: sensors powered before setup() to prevent
    mark_failed() on unpowered I2C devices
    - Keep sensors powered in prevent-sleep mode to preserve NAU7802
    register state; only power off before deep sl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
2026-09-05 fix: fz updates
    [BeeHive.fzz]
2026-09-06 feat: normalised averaged audio analysis, YAML thresholds, calibration fixes, CI
    bee_audio:
    - Welch-average `frames` consecutive FFT frames per reading (default 4)
    - Report band levels as one-sided PSD normalised by window energy and
    sample rate, so values are independent of fft_size
    - Expose thresholds, pre-swarm centroid and band edges as config options
    - Index bands by enum; collapse per-band setters and schema into loops
    - Scale I2S read timeout with frame length; release FFT tables on failure
    Package:
    - Battery level uses `method: exact` so the LiPo curve is interpolated
    piecewise rather than fitted to a single line
    - Hold battery level while solar current indicates charging; add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
    [bee_audio.cpp]
2026-09-06 feat: add modulation spectrum sensors for colony strength
    Implements the modulation spectrum feature from Abdollahi et al. 2026
    (arXiv 2607.20386) as two new bee_audio sensors. A 100 ms / 12.5 ms hop
    STFT of the 150-250 Hz band gives an 80 Hz amplitude envelope; a Welch
    FFT over 256-hop segments gives modulation power 0-40 Hz.
    - modulation_index: share of 1-40 Hz envelope power in 10-25 Hz, in
    percent, independent of gain and loudness
    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
2026-09-06 feat: power FeatherS3D via VBAT, use onboard MAX17048, single high-side INA226
    The HT7833 feeding the 3V3 pin left LDO2 unpowered, since its input is the
    VBAT/USB node, so the whole sensor rail was dead. The CN3065 output now feeds
    VBAT and the external LDO is dropped.
    Schematic: solar INA226 moved high-side with VBS on the charger side and A0/A1
    strapped to GND; battery INA226 removed in favour of the onboard MAX17048;
    INMP441 L/R tied to GND and I2S moved to GPIO1/3/7 to match the firmware.
    Firmware: replace the battery INA226 and voltage-curve level with a max17043
    sensor. Battery Current/Power/Shunt Voltage entities are removed and Battery
    Bus Voltage becomes Battery Voltage.
    Claude-S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
    [BeeHive.fzz]
2026-09-06 feat: add circuit skill that extracts nets from the Fritzing sketch
    fzz_nets.py reads the .fzz directly: part pin names, part-internal buses,
    schematic nets, breadboard/stripboard nets with strip cuts, and a diff that
    reports merged, stray, partial and unbuilt connections. Fritzing's XML
    netlist export is no longer needed.
    Ignore .claude/worktrees.
    Claude-Session: https://claude.ai/code/session_01NPSDBfkhSfcXZCVJP14dZs
2026-09-06 fix: Review circuit and improve
    [BeeHive.fzz]
2026-09-06 feat: stripboard layout on two pluggable boards
    Lay out the circuit in the Fritzing breadboard view on a 30x40 main board
    (FeatherS3D, INA226, NAU7802, C1, C2) and a 16x15 hive board (SHT40,
    INMP441, C3), joined by an 8-way JST-XH cable with ground between the I2C
    and I2S lines. Solar panel, CN3065 charger input and charger output plug in
    on 2-way sockets; the CN3065 and battery stay off-board. Add the sockets and
    cable to the schematic and regroup the hive-side parts. Leave INA226 A0/A1
    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
    [BeeHive.fzz]
2026-09-10 fix: OTA mode never kept the device awake
    The Home Assistant binary sensor publishes the first value it receives
    through publish_initial_state(), which state callbacks skip unless
    trigger_on_initial_state is set. The YAML schema defaults that option to
    false, and every wake is a fresh boot, so the on_state automation never
    ran and prevent_deep_sleep never turned on.
    Claude-Session: https://claude.ai/code/session_0182n8iWDGdXK6aZQrxFpxqX
2026-09-10 fix: always fetch the package and component from GitHub
    Track the default branch and set refresh: always on both the package and
    the external component so ESPHome re-fetches instead of using its cached
    clone. Drops the release-tag workflow, which is no longer used.
    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
2026-09-20 feat: configurable measurement interval in OTA mode
    Adds the ota_mode_interval substitution so load cell calibration doesn't have to wait five minutes between readings.
2026-09-20 fix: load cell ring wiring cancelled the bridge signal
    Joining white to black put a +d and a -d gauge in every bridge arm, so the output only responded to load imbalance between corners. Join like colours instead, and add a troubleshooting entry for the symptom.
2026-09-20 feat: Measure Now button to start a measurement cycle on demand
2026-09-20 fix: read the INMP441 as Philips I2S, not left-justified
    MSB framing latched one bit early, putting the sign bit in bit 30 so every negative sample read as near positive full scale. Sound level sat at about -1 dBFS in silence, the noise floor was 60 dB too high and tones grew square-wave harmonics that tripped the queenless bands.
    [bee_audio.cpp]
2026-09-20 fix: measure sound level above 60 Hz
    The raw-sample RMS was dominated by the microphone's DC offset and settling transient, reading about -33 dBFS in a room whose spectrum sums to -83 dBFS. Integrate the PSD from 60 Hz instead.
    [bee_audio.cpp]
2026-09-20 fix: board
    [BeeHive.fzz]
2026-09-21 feat: Home Assistant dashboard
    Overview, audio and power views to paste into the raw configuration editor.
2026-09-22 feat: 3D printable enclosures for the main board and hive board
    Parametric OpenSCAD model with exported STLs, a layout view showing where
    the boards, battery and charger sit, and rendered previews.
    [beehive-case.scad, box.stl, clamp.stl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]
2026-09-22 fix: seal the enclosure lid with an O-ring and close it flush
    The lid pads held it off the rim and the wide foam recess had no defined
    compression. A 3 mm cord now sits in a rim groove squeezed 23% by the flush
    lid, with eight screws, a locating skirt and larger corner radii.
    [beehive-case.scad, box.stl, clamp.stl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]
2026-09-22 fix: size the lid seal groove for a stock 2.4 mm O-ring
    Large 3 mm cross-section rings are hard to find locally; a 155 mm OD x
    2.4 mm nitrile ring drops into the groove with about 2% stretch.
    [beehive-case.scad, box.stl, fitcheck.stl]
2026-09-24 fix: take readings before connecting so Home Assistant never sees unknown
    Home Assistant subscribed during the wake window before sensors were read,
    so every entity flipped to unknown and back on each wake, retriggering
    state automations and resetting last_changed.
2026-09-26 fix: make the enclosures easier to print and assemble
    - Heat-set inserts replace self-tappers and the lid's captive nuts, so
    every joint is one M3 x 10 screw into one M3 x 5.7 insert. Insert
    holes are chamfered so displaced plastic can't lift the lid off the
    lugs.
    - A downturned lip stiffens the lid between screws and keeps rain off
    the rim seam.
    - The seal groove is 1.8 mm, a whole number of layers, for a
    predictable 25% squeeze.
    - Glands are 30 mm apart so their nuts can't clash; the middle lugs
    move 2.6 mm to make room.
    - Lugs reach into the wall so the corner ones meet its curve without a
    gap.
    - Hive lid pegs become ribs joined to the side walls, and the
    counterbores get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
    [beehive-case.scad, box.stl, fitcheck.stl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]
2026-09-26 docs: hold the battery down with a removable mounting strip
    The guides only locate the battery sideways; a pull-tab strip keeps it
    from moving without having to pry the pouch off the floor later.
2026-09-26 fix: open the hive lid vent holes through the top plate
    The lid cavity was modelled 2 mm low, leaving a 1 mm skin under the top
    grid that sealed the microphone and SHT40 off from the hive and left
    components 1 mm less headroom than intended.
    [beehive-case.scad, hive_lid.stl]
2026-09-26 fix: print the gland and vent holes without support
    The round tops of the side-wall holes printed in mid-air. They are now
    45 degree teardrops cut flat 0.6 mm above the circle, which bridges
    cleanly and stays inside the gland and vent sealing washers.
    [beehive-case.scad, box.stl]
2026-09-26 fix: fit the case to the measured components
    Resize the main board, battery, charger and hive board to measured sizes,
    and shrink the rear board post and clamp ledges so the battery no longer
    hits them. Take the solar wires through a PG7 gland.
    Generate the hive images from the model, add an A1 mini PrusaSlicer
    profile to validate printability, and print with 4 walls and 35% infill.
    [beehive-case.scad, box.stl, clamp.stl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]
2026-10-17 fix: wait for the NAU7802 to settle before reading weight
    After a cold boot the NAU7802 only starts converting 600ms after setup, so
    the 7 reads saw too few samples for the median filter to publish and weight
    stayed unknown on every wake since readings moved ahead of the WiFi connect.
2026-10-18 fix: let the microphone finish starting up before recording
    The INMP441 outputs zeros for 2^18 SCK cycles after power-up. At 8 kHz SCK
    is only 512 kHz, so that is 512 ms, but only 96 ms was discarded and the
    first audio frame of every wake was silent, pulling all levels down.
2026-10-18 fix: warm the load cells during the audio capture and sleep on a fixed interval
    The NAU7802 powers the load cells from a timer that could not fire while the
    audio capture blocked the loop, so weight was read from cells powered for
    about a second. Start it first, read weight after the audio, and collect 7
    valid samples so each median only uses the current cycle.
    Also make the sensor rail settle actually block setup, wait for a client
    subscribed to states rather than any API client, and subtract the awake time
    from the sleep so cycles start every 5 minutes.
2026-10-19 fix: wire colours
2026-10-19 fix: read the INA226 after its first conversion completes
    Reading it straight after setup returned 0 for bus voltage, current and
    power, as only the shunt register had been written. Read it after the
    load cell warm-up delay instead.
2026-10-19 feat: show when the hive monitor last woke
    Home Assistant only moves last_updated when a value changes, so the device
    publishes its own wake time as a timestamp text sensor (a float timestamp
    only resolves to ~2 minutes), using the time synced from Home Assistant.
    The dashboard overview shows it as a tile.
2026-10-19 Revert "fix: publish the wake time before connecting"
    This reverts commit 90fc76e. The missed updates were wakes during OTA mode,
    where the device stays awake and the wake time correctly does not change.
